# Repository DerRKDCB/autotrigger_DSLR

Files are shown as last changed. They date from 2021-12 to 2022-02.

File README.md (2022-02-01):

# autotrigger_DSLR
Device to automaticly take a number of long exposure pictures designed for astrophotography. 
Works with any DSLR that has a 2.5mm jack remote trigger connector and a bulb exposure mode. Here is a [Video](https://www.youtube.com/watch?v=2kZ-wBnaWUU "Video") with the device in Action

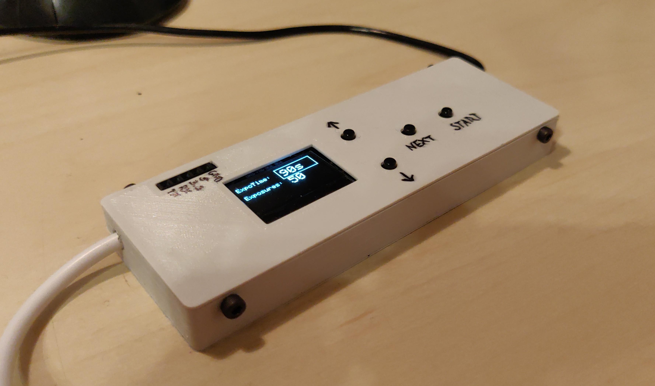
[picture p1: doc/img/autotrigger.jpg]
autotrigger_DSLR


## How to use
The device uses a 2.5mm headphoe jack to simulate an remote trigger. It is powered my USB. Uses SSD1306 OLED Display as Display. With 4 buttons you can change the exposure time and the number of Pictures to take. The controller is an ESP8266 (ESP-12F module), so wifi capabilities could be implemented (**but are not, yet**).

setup overview autotrigger_DSLR

1. Plug the USB into any USB Power source (Powerbank/Phone Charger/...) to power the device. Power consumtion is only 50mA so any Power source should work. Make sure you have a Power source that doesn't switch off because not enough current is detected.
2. Plug the headphone jack into the external/remote trigger socket of the camera.
3. Turn on the camera and change the settings to bulb mode for long exposures, if you want short exposures (under 1s) adjust exposure time at the camera accordingly.
4. Change exposure time on the autotrigger with the UP and DOWN buttons. (1s - 300s, range can be changed in code)
5. Press NEXT to select number of Exposures.
6. Change number of exposures to how much exposures you want UP and DOWN buttons. (1 - 100, range can be changed in code)
7. Press START to start the configured Series of Exposures.
8. While one Session is runnig, some info is displayed (exposure number, time of current exposure, total time)
9. Wait until session is finished or press NEXT to abort an session (current exposue will be finished)

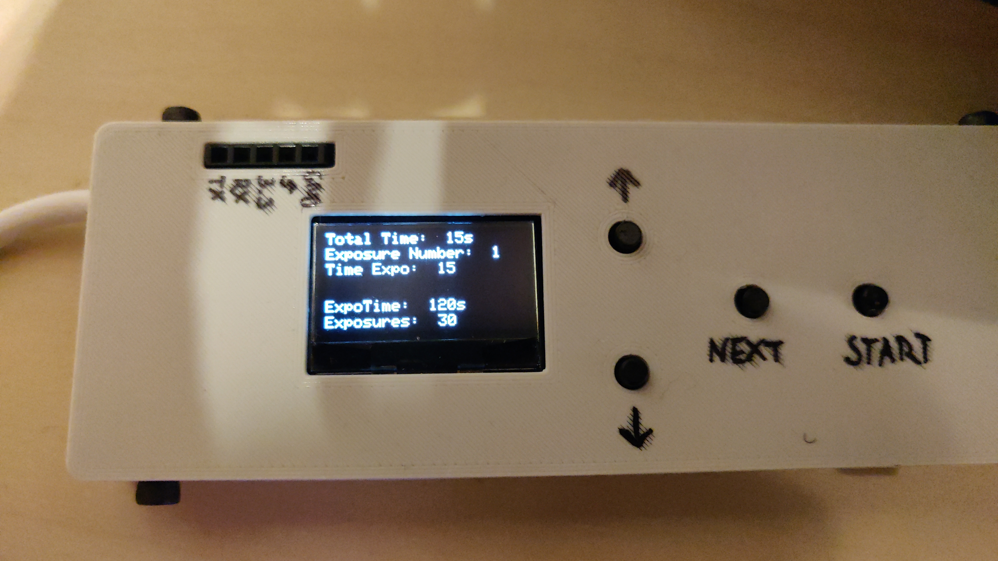
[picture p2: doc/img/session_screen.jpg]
session_screen


## Building

### Ordering PCB and Parts

Order the PCB from a manufacturer you like, i use [JLCPCB](https://jlcpcb.com/ "JLCPCB"), by uploading the [prepared gerber files](KiCAD/autotrigger_dslr_v1.zip).

#### Partslist:
| Part  | Value  | Package  | Comment  | Link  |
| --- | --- | --- | --- | --- |
| C1  | 10uF  | 0805  | | https://www.lcsc.com/product-detail/Multilayer-Ceramic-Capacitors-MLCC-SMD-SMT_FH-Guangdong-Fenghua-Advanced-Tech-0805X106M160NT_C2832123.html  |
| C2  | 10uF  | 0805  | | https://www.lcsc.com/product-detail/Multilayer-Ceramic-Capacitors-MLCC-SMD-SMT_FH-Guangdong-Fenghua-Advanced-Tech-0805X106M160NT_C2832123.html  |
| C3  | 100nF  | 0805  | | https://www.lcsc.com/product-detail/Multilayer-Ceramic-Capacitors-MLCC-SMD-SMT_FH-BK-Guangdong-Fenghua-Bangke-Elec-0805B104J500NT_C2830722.html  |
| C4  | 10uF  | 0805  | | https://www.lcsc.com/product-detail/Multilayer-Ceramic-Capacitors-MLCC-SMD-SMT_FH-Guangdong-Fenghua-Advanced-Tech-0805X106M160NT_C2832123.html  |
| C5  | 100nF  | 0805  | | https://www.lcsc.com/product-detail/Multilayer-Ceramic-Capacitors-MLCC-SMD-SMT_FH-BK-Guangdong-Fenghua-Bangke-Elec-0805B104J500NT_C2830722.html  |
| D1  | 1N5819  | SOD-123  | | https://www.lcsc.com/product-detail/Schottky-Barrier-Diodes-SBD_ZHIDE-1N5819W_C2683619.html  |
| D2  | 1N5819  | SOD-123 | | https://www.lcsc.com/product-detail/Schottky-Barrier-Diodes-SBD_ZHIDE-1N5819W_C2683619.html  |
| F1  | 500mA  | 1812  | Polyfuse  | https://www.lcsc.com/product-detail/Resettable-Fuses_TECHFUSE-mSMD050-15V_C70110.html  |
| J1  | | 5x2.54mm  | Pin Header Female  | https://www.lcsc.com/product-detail/Female-Headers_Ckmtw-Shenzhen-Cankemeng-B-2200S05P-A120_C124414.html  |
| J2  | SSD1306  | SSD1306  | Display, look for pinout *GND VCC SCL SDA* , 4Pin, White | https://www.aliexpress.com/item/32638662748.html |
| K1  | G6K  | G6K-2F  | Omron Relay  | https://www.lcsc.com/product-detail/Signal-Relays_Omron-Electronics-G6K-2F-Y-TR-DC5_C47190.html  |
| Q1  | MosFET  | SOT-23  | N-Channel  | https://www.lcsc.com/product-detail/MOSFETs_Sinopower-Semicon-SM2326NSANC-TRG_C368561.html  |
| R1  | 10k  | 0805  | | https://www.lcsc.com/product-detail/Chip-Resistor-Surface-Mount_TyoHM-RMC080510K1-N_C269742.html  |
| R2  | 10k  | 0805  | | https://www.lcsc.com/product-detail/Chip-Resistor-Surface-Mount_TyoHM-RMC080510K1-N_C269742.html  |
| R3  | 1k  | 0805  | | https://www.lcsc.com/product-detail/Chip-Resistor-Surface-Mount_TyoHM-RMC08051K5-N_C269727.html  |
| R4  | 10k  | 0805  | | https://www.lcsc.com/product-detail/Chip-Resistor-Surface-Mount_TyoHM-RMC080510K1-N_C269742.html  |
| R5  | 5k  | 0805  | | https://www.lcsc.com/product-detail/Chip-Resistor-Surface-Mount_Viking-Tech-ARG05DTC5001_C2828783.html  |
| R6  | 5k  | 0805  | | https://www.lcsc.com/product-detail/Chip-Resistor-Surface-Mount_Viking-Tech-ARG05DTC5001_C2828783.html  |
| R7  | 5k  | 0805  | | https://www.lcsc.com/product-detail/Chip-Resistor-Surface-Mount_Viking-Tech-ARG05DTC5001_C2828783.html  |
| R8  | 5k  | 0805  | | https://www.lcsc.com/product-detail/Chip-Resistor-Surface-Mount_Viking-Tech-ARG05DTC5001_C2828783.html  |
| R9  | 1k  | 0805  | | https://www.lcsc.com/product-detail/Chip-Resistor-Surface-Mount_TyoHM-RMC08051K5-N_C269727.html  |
| R10  | 10k  | 0805  | | https://www.lcsc.com/product-detail/Chip-Resistor-Surface-Mount_TyoHM-RMC080510K1-N_C269742.html  |
| R11  | 1k  | 0805  | | https://www.lcsc.com/product-detail/Chip-Resistor-Surface-Mount_TyoHM-RMC08051K5-N_C269727.html  |
| SW1  | pushbutton  | SPST SMD  | | https://www.lcsc.com/product-detail/Tactile-Switches_XKB-Connectivity-TS-1101-C-W_C318938.html  |
| SW2  | pushbutton  | SPST SMD  | | https://www.lcsc.com/product-detail/Tactile-Switches_XKB-Connectivity-TS-1101-C-W_C318938.html  |
| SW3  | pushbutton  | THT 6x6x10mm  | | https://www.lcsc.com/product-detail/Tactile-Switches_G-Switch-GT-TC096A-H100-L1_C963363.html  |
| SW4  | pushbutton  | THT 6mm_H9.5mm  | | https://www.lcsc.com/product-detail/Tactile-Switches_G-Switch-GT-TC096A-H100-L1_C963363.html  |
| SW5  | pushbutton  | THT 6mm_H9.5mm  | | https://www.lcsc.com/product-detail/Tactile-Switches_G-Switch-GT-TC096A-H100-L1_C963363.html  |
| SW6  | pushbutton  | THT 6mm_H9.5mm  | | https://www.lcsc.com/product-detail/Tactile-Switches_G-Switch-GT-TC096A-H100-L1_C963363.html  |
| U1  | ESP8266  | ESP-12F  | | https://www.lcsc.com/product-detail/WiFi-Modules_Ai-Thinker-ESP-12F-ESP8266MOD_C82891.html  |
| U2  | AMS1117-3.3  | SOT-223-3  | | https://www.lcsc.com/product-detail/Linear-Voltage-Regulators-LDO_PUOLOP-AMS1117-3-3_C351784.html  |

#### You also need:
- 1x USB A cable (any can be used because it's solderd directly to the pcb)
- 1x 2.5mm headphone jack cable https://www.aliexpress.com/item/4001182848617.html
- 8x M2.5 5mm bolts https://www.aliexpress.com/item/32963722509.html
- cable ties for strain relief
- tape (electrical/kepton/... doesn't really matter)
- For programming: USB to serial Adapter and jumper cables

### 3D Printing
Print [case](FreeCAD/3dp/stl/case-case.stl) and [lid](FreeCAD/3dp/stl/case-led.stl) in PLA (recommended, but doesn't really matter) and standard settings.

### Soldering

1. Start soldering all SMD components, using the [schematic](doc/autotrigger_DSLR_v1_schematic.pdf) and the partslist above. Diode cathodes are indicated with "-".
2. Solder Programming Pin headers and THT pushbuttons.
3. Isolate the backside of the SSD1306 OLED Display with some tape, then solder in place.
4. Before soldering wires put them though holes in the case.
5. USB A cable: strip wire and check which is +5V (propably red) and GND (propably black) using a multimeter. Then solder to J4.
6. Headphone Jack cable: cut away female jack. Strip wire and tin the tips so that the isolating coating is burnt way (thats the way i do it). Then check which are the needed wires (multimeter continuity) and solder to J3, according to picture below.
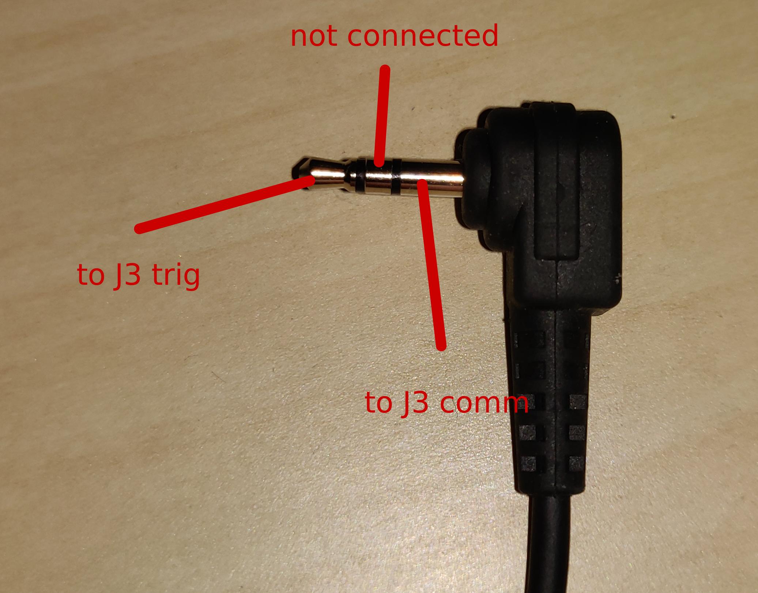
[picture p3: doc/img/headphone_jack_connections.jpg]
headphone_jack_connections


### Assembly

1. Screw PCB to case using four M2.5 bolts.
2. Put a zip tie around both cables to wirk as strain relief.
3. Now upload software to the autotrigger, see *Configuration and Programming* section.
4. Screw lid to case using four M2.5 bolts.

## Configuration and Programming

1. autotrigger_DSLR is programmed in the [PlatformIO IDE](https://docs.platformio.org/en/latest/integration/ide/vscode.html#ide-vscode "PlatformIO IDE"). PlatformIO is needed to upload the Software to the autotrigger.
2. Open Project in PlatformIO
3. Open [src/main.cpp](src/main.cpp)
4. Change function options at the top of the document, if needed (more explosures, longer exposures, ...)
```cpp
//Function Options
#define minExposure 1000 //minimum exposure time in ms
#define maxExposure 300000 //maximum exposure time in ms
#define minNumberOfExposures 1
#define maxNumberOfExposures 100 //absolute max 255
#define waitingTimeBetweenExposures 2000 //time the controller waits for camera until it starts the next exposure
```
5. If buttons don't work properly, you may have to increase `buttonTolerance` or adjust button values
```cpp
//Button Values
#define valueButtonUp 588
#define valueButtonDown 328
#define valueButtonNext 231
#define valueButtonStart 181
#define buttonTolerance 10
```
6. Connect the autotrigger via USB to Serial Adapter. Only connect 5V **OR** 3.3V

| Serial Adapter  | autotrigger  |
| --- | --- |
| GND  | GND  |
| 5V  | 5  |
| **or** 3.3V  | **or** 3.3  |
| TX  | RX  |
| RX  | TX  |

7. Hit Upload, press both boot and reset button, release reset button, wait till upload has started, release boot button.
8. Wait until upload is finished.
9. press reset.
10. **ENJOY**

## Todo
- Mounting holes PCB need adjusdment, false measurement

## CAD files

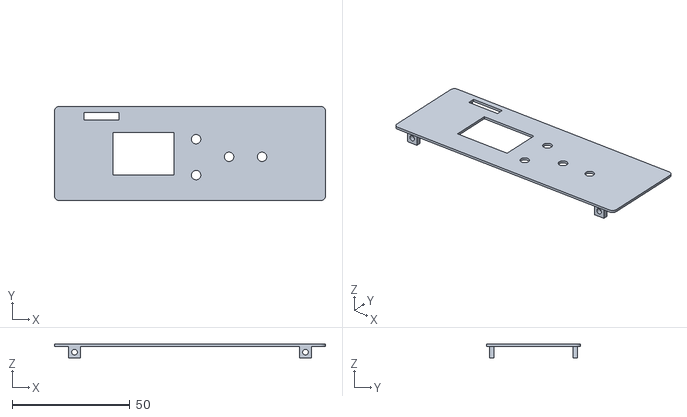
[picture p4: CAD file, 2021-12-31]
FreeCAD/3dp/stl/case-lid.stl
115.0 x 40.0 x 6.00

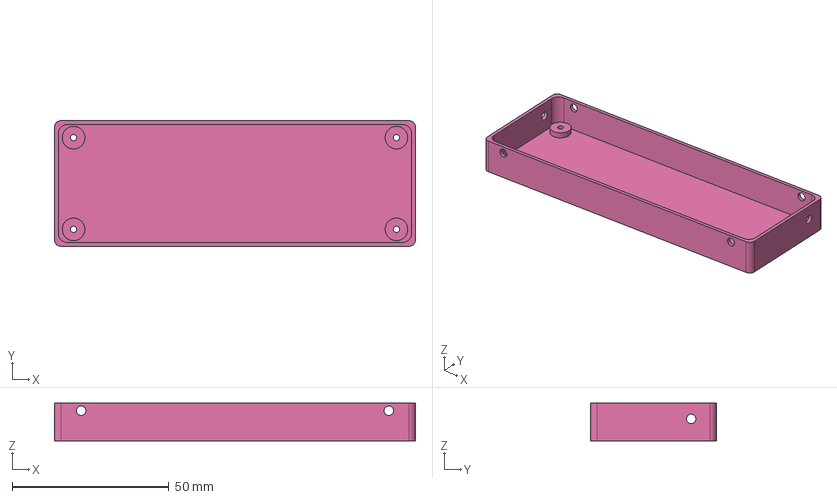
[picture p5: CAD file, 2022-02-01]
FreeCAD/case.FCStd
115.0 x 40.0 x 12.0 mm

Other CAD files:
FreeCAD/3dp/stl/case-case.stl

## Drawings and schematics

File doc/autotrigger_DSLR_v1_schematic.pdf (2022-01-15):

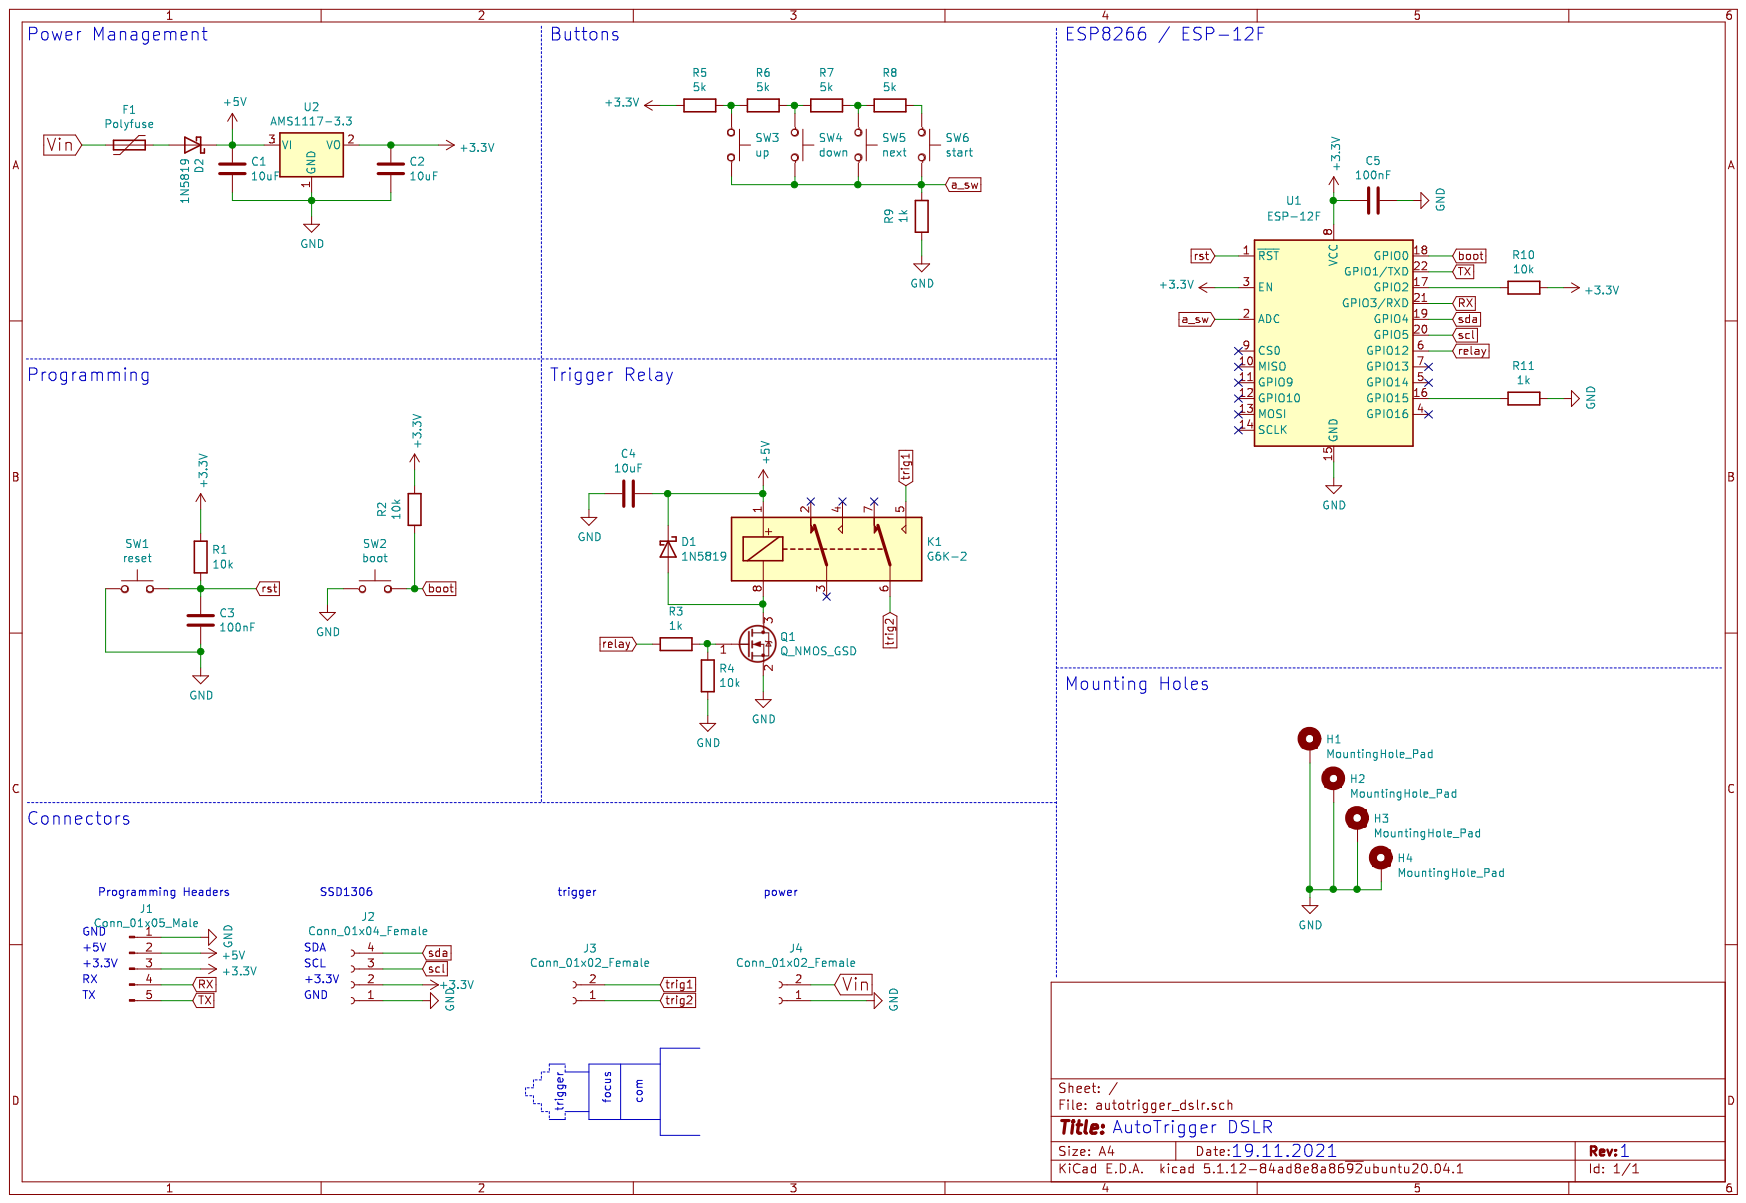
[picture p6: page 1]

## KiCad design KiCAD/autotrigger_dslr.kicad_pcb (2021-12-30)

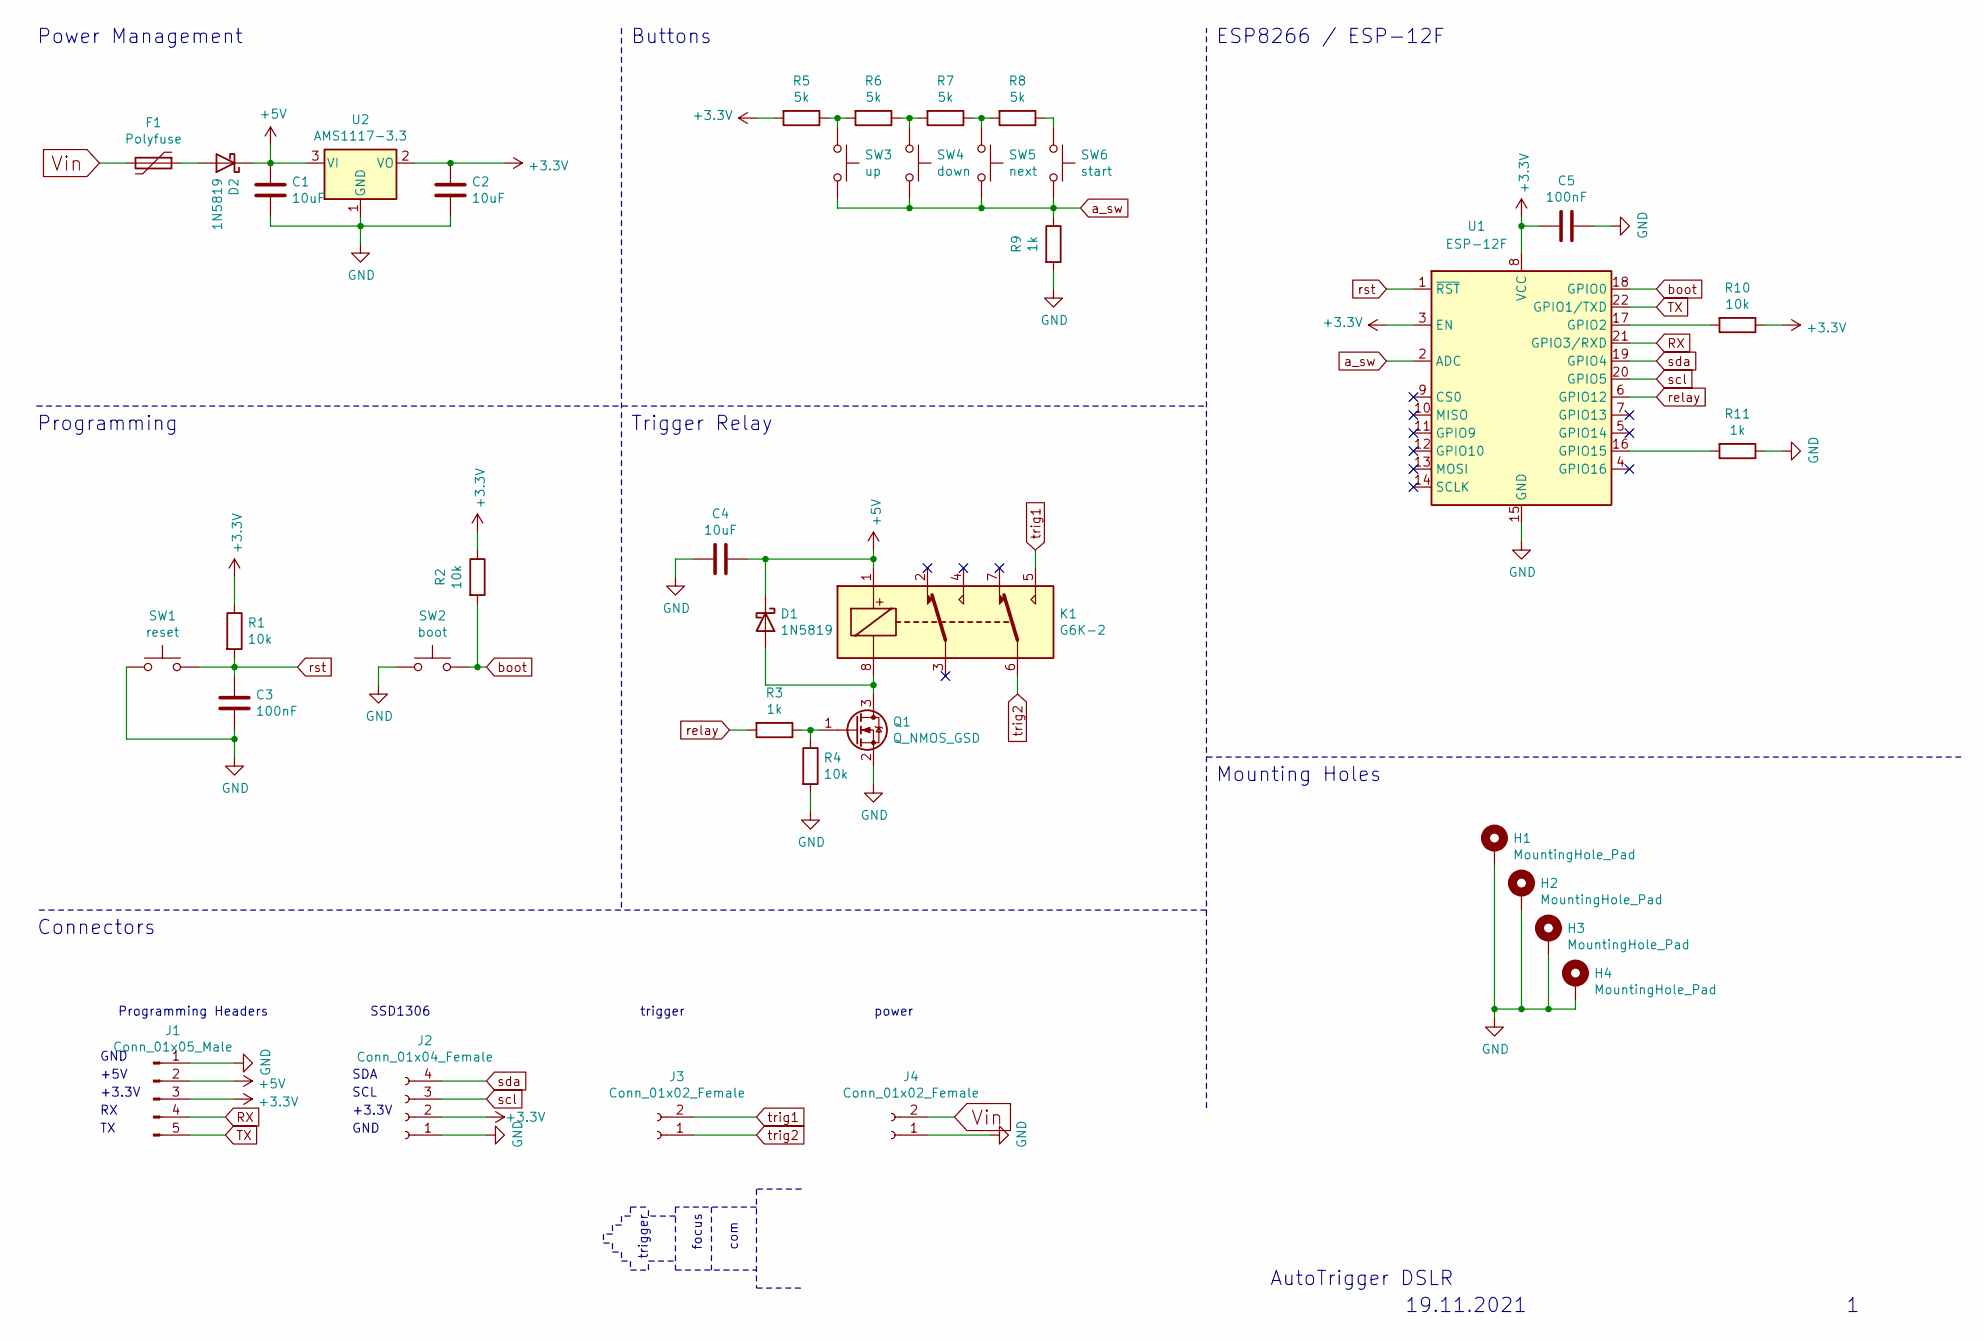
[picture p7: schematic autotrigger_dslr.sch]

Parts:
C1, C2, C4: 10uF; C_0805_2012Metric_Pad1.18x1.45mm_HandSolder
C3, C5: 100nF; C_0805_2012Metric_Pad1.18x1.45mm_HandSolder
D1, D2: 1N5819; D_SOD-123
F1: Polyfuse; Fuse_1812_4532Metric_Pad1.30x3.40mm_HandSolder
H1, H2, H3, H4: MountingHole_Pad; MountingHole_2.7mm_M2.5_Pad
J1: Conn_01x05_Male; PinHeader_1x05_P2.54mm_Vertical
J2: Conn_01x04_Female; PinHeader_1x04_P2.54mm_Vertical
J3, J4: Conn_01x02_Female; PinHeader_1x02_P2.54mm_Vertical
K1: G6K-2; Relay_DPDT_Omron_G6K-2F-Y
Q1: Q_NMOS_GSD; SOT-23_Handsoldering
R1, R2, R4, R10: 10k; R_0805_2012Metric_Pad1.20x1.40mm_HandSolder
R3, R9, R11: 1k; R_0805_2012Metric_Pad1.20x1.40mm_HandSolder
R5, R6, R7, R8: 5k; R_0805_2012Metric_Pad1.20x1.40mm_HandSolder
SW1: reset; SW_SPST_FSMSM
SW2: boot; SW_SPST_FSMSM
SW3: up; SW_PUSH_6mm_H9.5mm
SW4: down; SW_PUSH_6mm_H9.5mm
SW5: next; SW_PUSH_6mm_H9.5mm
SW6: start; SW_PUSH_6mm_H9.5mm
U1: ESP-12F; ESP-12E
U2: AMS1117-3.3; SOT-223-3_TabPin2

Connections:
+3V3: C2.1, C5.2, J1.3, J2.2, R1.1, R2.1, R5.2, R10.1, U1.3 (EN), U1.8 (VCC), U2.2 (VO)
+5V: C1.1, C4.1, D1.1 (K), D2.1 (K), J1.2, K1.1, U2.3 (VI)
GND: C1.2, C2.2, C3.2, C4.2, C5.1, H1.1, H2.1, H3.1, H4.1, J1.1, J2.1, J4.1, Q1.2 (S), R4.2, R9.2, R11.1, SW1.1, SW2.1, U1.15 (GND), U2.1 (GND)
unnamed: D1.2 (A), K1.8, Q1.3 (D)
unnamed: D2.2 (A), F1.1
unnamed: Q1.1 (G), R3.1, R4.1
unnamed: R5.1, R6.2, SW3.1
unnamed: R6.1, R7.2, SW4.1
unnamed: R7.1, R8.2, SW5.1
unnamed: R8.1, SW6.1
unnamed: R10.2, U1.17 (GPIO2)
unnamed: R11.2, U1.16 (GPIO15)
RX: J1.4, U1.21 (GPIO3/RXD)
TX: J1.5, U1.22 (GPIO1/TXD)
Vin: F1.2, J4.2
a_sw: R9.1, SW3.2, SW4.2, SW5.2, SW6.2, U1.2 (ADC)
boot: R2.2, SW2.2, U1.18 (GPIO0)
relay: R3.2, U1.6 (GPIO12)
rst: C3.1, R1.2, SW1.2, U1.1 (~RST)
scl: J2.3, U1.20 (GPIO5)
sda: J2.4, U1.19 (GPIO4)
trig1: J3.2, K1.5
trig2: J3.1, K1.6

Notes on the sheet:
GND
+5V
+3.3V
SCL
SDA
Programming Headers
SSD1306
trigger
com
focus
power
Connectors
Programming
Trigger Relay
Buttons
Power Management
ESP8266 / ESP-12F
19.11.2021
AutoTrigger DSLR
Mounting Holes

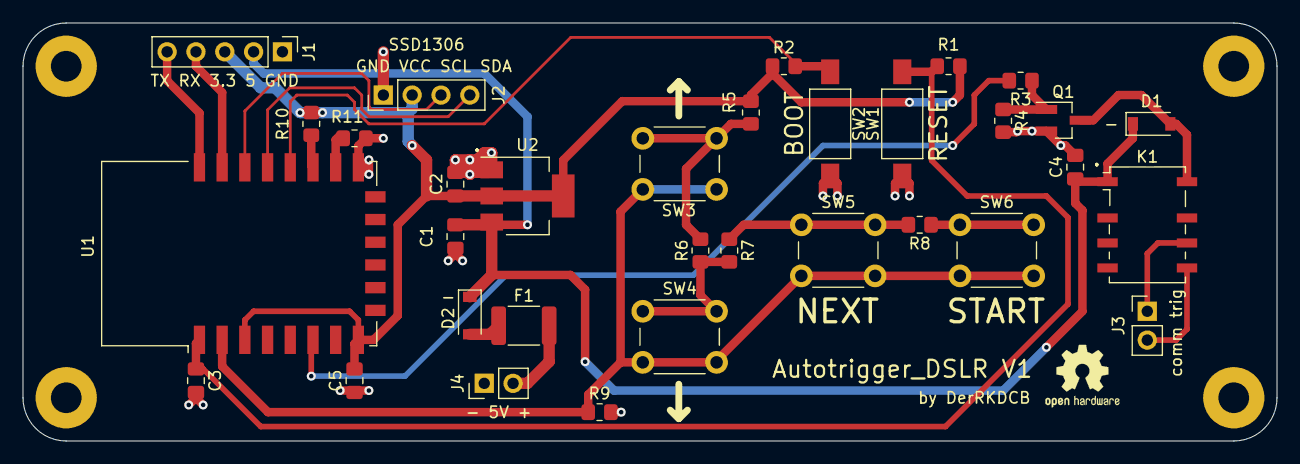
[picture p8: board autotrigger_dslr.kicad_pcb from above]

Board: 2 copper layers, 110.5 x 36.8 mm, 38 parts (1 on the bottom side), 23 nets.

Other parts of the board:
QR*****: DerRKDCB; Rickroll

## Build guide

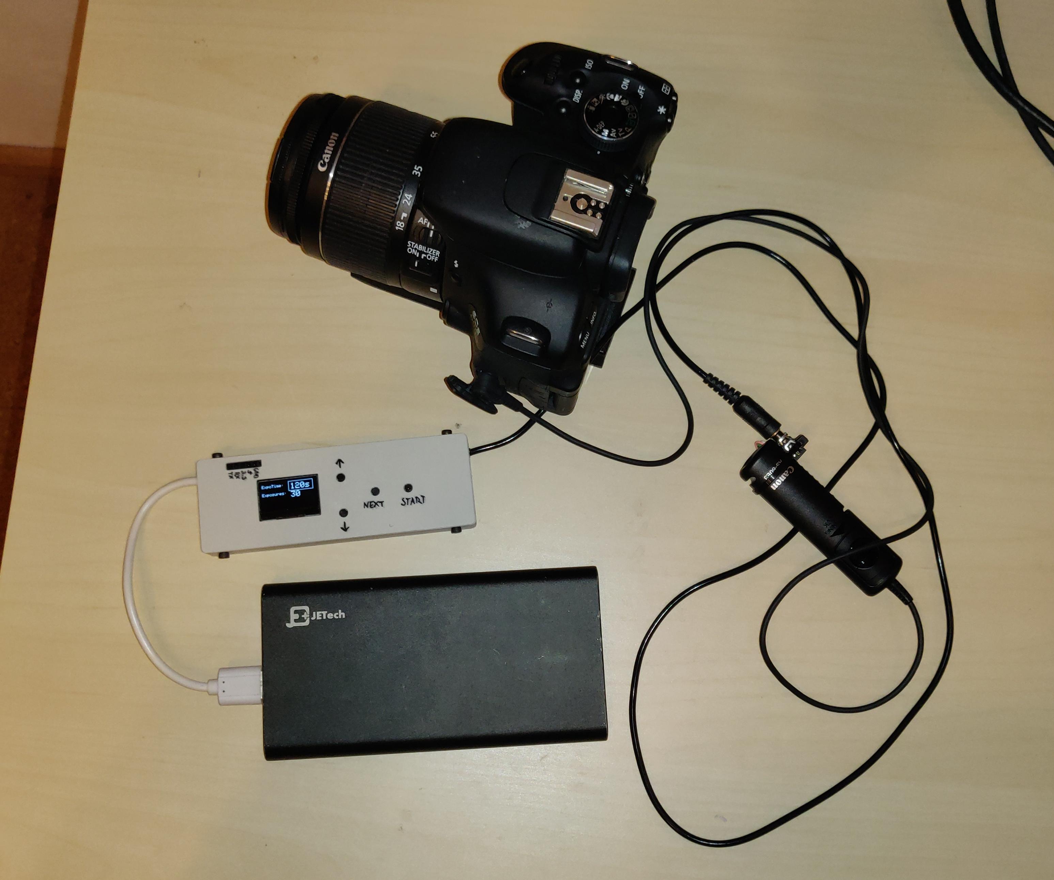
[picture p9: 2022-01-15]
doc/img/setup.jpg

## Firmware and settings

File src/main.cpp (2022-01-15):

#include <Arduino.h>
#include <SPI.h>
#include <Wire.h>
#include <Adafruit_GFX.h>
#include <Adafruit_SSD1306.h>

//Pin Definitions
#define pinAnalogButtonInput A0
#define pinRelayTrigger D6

//Button Values
#define valueButtonUp 588
#define valueButtonDown 328
#define valueButtonNext 231
#define valueButtonStart 181
#define buttonTolerance 10

//Function Options
#define minExposure 1000 //minimum exposure time in ms
#define maxExposure 300000 //maximum exposure time in ms
#define minNumberOfExposures 1
#define maxNumberOfExposures 100 //absolute max 255
#define waitingTimeBetweenExposures 2000 //time the controller waits for camera until it starts the next exposure in ms

//OLED
#define SCREEN_WIDTH 128    // OLED display width, in pixels
#define SCREEN_HEIGHT 64    // OLED display height, in pixels
#define OLED_RESET -1       // Reset pin # (or -1 if sharing Arduino reset pin)
#define SCREEN_ADDRESS 0x3C ///< See datasheet for Address; 0x3D for 128x64, 0x3C for 128x32
Adafruit_SSD1306 display(SCREEN_WIDTH, SCREEN_HEIGHT, &Wire, OLED_RESET);

//Global Variables
bool isExposing = false;
byte numberOfExposures = 30;
unsigned long exposureTime = 120000;
byte settingSelected = 1;
byte exposureCounter = 0;
unsigned long startedSessionAtMillis = 0;
bool abortSession = false;
unsigned long startMillis; //used for calculation dime spent in exposing and waiting

void increaseExposure(void)
{
  exposureTime += 1000;           //increase 1s exposure time
  if (exposureTime > maxExposure) //roll over to defined minExposure
  {
    exposureTime = minExposure;
  }
}

void decreaseExposure(void)
{
  exposureTime -= 1000;           //decrease 1s exposure time
  if (exposureTime < minExposure) //roll over to defined maxExposure
  {
    exposureTime = maxExposure;
  }
}

void increaseNumberOfExposures(void)
{
  numberOfExposures++;                          //increase number of exposures
  if (numberOfExposures > maxNumberOfExposures) //roll over to defined minNumberOfExposures
  {
    numberOfExposures = minNumberOfExposures;
  }
}

void decreaseNumberOfExposures(void)
{
  numberOfExposures--;                          //decrease number of exposures
  if (numberOfExposures < minNumberOfExposures) //roll over to defined maxNumberOfExposures
  {
    numberOfExposures = maxNumberOfExposures;
  }
}

void nextSetting(void)
{
  settingSelected++;       //increase Setting
  if (settingSelected > 2) //Roll over
  {
    settingSelected = 1;
  }
}

void startSession(void)
{
  exposureCounter = 0;
  isExposing = true;
  startedSessionAtMillis = millis();
  exposureCounter = 1;
  abortSession = false;
}

void displaySettingsScreen(void)
{
  display.clearDisplay();

  //Exposure Time
  display.setCursor(0, 5);
  display.setTextSize(1);
  display.print(F("ExpoTime:  "));
  display.setCursor(70, 5);
  display.setTextSize(2);
  display.print(exposureTime / 1000);
  display.print(F("s"));
  if (settingSelected == 1) // highlight if selected
  {
    display.drawRect(65, 0, 60, 24, SSD1306_WHITE);
  }

  //Number of Exposures
  display.setCursor(0, 25);
  display.setTextSize(1);
  display.print(F("Exposures:  "));
  display.setCursor(70, 25);
  display.setTextSize(2);
  display.print(numberOfExposures);
  if (settingSelected == 2) // highlight if selected
  {
    display.drawRect(65, 20, 60, 24, SSD1306_WHITE);
  }

  display.display();
}

void handleButtonsInSettings()
{
  int buttonvalue = analogRead(pinAnalogButtonInput);

  if (buttonvalue <= valueButtonUp + buttonTolerance && buttonvalue >= valueButtonUp - buttonTolerance) //UP
  {
    if (settingSelected == 1)
    {
      increaseExposure();
    }
    else if (settingSelected == 2)
    {
      increaseNumberOfExposures();
    }
  }

  if (buttonvalue <= valueButtonDown + buttonTolerance && buttonvalue >= valueButtonDown - buttonTolerance) //DOWN
  {
    if (settingSelected == 1)
    {
      decreaseExposure();
    }
    else if (settingSelected == 2)
    {
      decreaseNumberOfExposures();
    }
  }

  if (buttonvalue <= valueButtonNext + buttonTolerance && buttonvalue >= valueButtonNext - buttonTolerance) //NEXT
  {
    nextSetting();
  }

  if (buttonvalue <= valueButtonStart + buttonTolerance && buttonvalue >= valueButtonStart - buttonTolerance) //START
  {
    startSession();
  }
}

void handleButtonsInSession()
{
  int buttonvalue = analogRead(pinAnalogButtonInput);

  if (buttonvalue <= valueButtonUp + buttonTolerance && buttonvalue >= valueButtonUp - buttonTolerance) //UP
  {
  }

  if (buttonvalue <= valueButtonDown + buttonTolerance && buttonvalue >= valueButtonDown - buttonTolerance) //DOWN
  {
  }

  if (buttonvalue <= valueButtonNext + buttonTolerance && buttonvalue >= valueButtonNext - buttonTolerance) //NEXT
  {
    abortSession = true;
  }

  if (buttonvalue <= valueButtonStart + buttonTolerance && buttonvalue >= valueButtonStart - buttonTolerance) //START
  {
    //
  }
}

void displayExposureScreen(bool waiting)
{
  display.clearDisplay();

  //Total Time
  display.setCursor(0, 0);
  display.setTextSize(1);
  display.print(F("Total Time:  "));
  display.print((millis() - startedSessionAtMillis) / 1000);
  display.print(F("s"));

  //Exposure Number
  display.setCursor(0, 10);
  display.setTextSize(1);
  display.print(F("Exposure Number:  "));
  display.print(exposureCounter);

  //Current Exposure Time
  display.setCursor(0, 20);
  display.setTextSize(1);
  display.print(F("Time Expo:  "));
  if (waiting)
  {
    display.print(F("waiting"));
  }
  else
  {
    int timeSpentInExposure = (exposureTime - (startMillis + exposureTime - millis())) / 1000;
    display.print(timeSpentInExposure);
  }

  //Abort Session
  if (abortSession)
  {
    display.setCursor(90, 54);
    display.setTextSize(1);
    display.print(F("ABORT"));
  }

  //Settings
  display.setCursor(0, 44);
  display.setTextSize(1);
  display.print(F("ExpoTime:  "));
  display.print(exposureTime / 1000);
  display.print(F("s"));
  display.setCursor(0, 54);
  display.setTextSize(1);
  display.print(F("Exposures:  "));
  display.print(numberOfExposures);

  display.display();
}

void setup()
{
  Serial.begin(9600);

  pinMode(pinRelayTrigger, OUTPUT);
  digitalWrite(pinRelayTrigger, LOW);

  // SSD1306_SWITCHCAPVCC = generate display voltage from 3.3V internally
  if (!display.begin(SSD1306_SWITCHCAPVCC, SCREEN_ADDRESS))
  {
    Serial.println(F("SSD1306 allocation failed"));
    for (;;)
      ; // Don't proceed, loop forever
  }

  // Clear the buffer
  display.clearDisplay();
  display.setTextColor(SSD1306_WHITE); // Draw white text
  display.cp437(true);                 // Use full 256 char 'Code Page 437' font

  delay(200); //Sanity delay
}

void loop()
{

  while (!isExposing) //Settings
  {
    displaySettingsScreen();
    handleButtonsInSettings();
    delay(100); //tick for settings is 100ms
  }

  while (isExposing) //Exposing
  {

    startMillis = millis();
    while (startMillis + exposureTime > millis())
    {
      digitalWrite(pinRelayTrigger, HIGH);
      displayExposureScreen(false);
      handleButtonsInSession();
    }

    startMillis = millis();
    while (startMillis + waitingTimeBetweenExposures > millis()) //Waiting
    {
      digitalWrite(pinRelayTrigger, LOW);
      displayExposureScreen(true);
      handleButtonsInSession();
    }

    exposureCounter++;
    if (exposureCounter > numberOfExposures || abortSession)
    {
      isExposing = false;
    }
  }
}

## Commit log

2021-12-30 add freecad case file
    [case.FCStd]
2021-12-30 added kicad files
    [autotrigger_dslr-B_Cu.gbr, autotrigger_dslr-B_Mask.gbr, autotrigger_dslr-B_Paste.gbr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]
2021-12-30 add pcb step to freecad
    [case.FCStd]
2021-12-30 designed case
    [case.FCStd]
2021-12-31 stl and slicing
    [CE3PRO_case-lid_and_case.3mf, case-case.stl, case-lid.stl]
2022-01-01 rename folder
    [case-case.stl, case-lid.stl]
2022-01-06 remove gcode files
    [CE3PRO_case-lid_and_case.3mf]
2022-01-06 show current exposure time
2022-01-15 regenerated gerber files
    [autotrigger_dslr-B_Cu.gbr, autotrigger_dslr-B_Mask.gbr, autotrigger_dslr-B_Paste.gbr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]
2022-01-15 add soldering and assembly
2022-01-15 link gerber files
2022-01-15 doc img and schematic
2022-02-01 screw holes PCB trough hole
    [case.FCStd]
2022-02-01 remove todo screwholes
